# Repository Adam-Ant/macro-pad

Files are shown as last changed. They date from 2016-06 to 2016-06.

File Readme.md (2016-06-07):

# Macro Pad
A project for designing a macro pad to allow complex functions to be mapped to dedicated buttons, using the low cost Arduino Pro Micro. The pad functions by using the inbuilt features of the ATMega32u4 used on the Pro Micro to emulate a gamepad, allowing the buttons to be mapped to many functions. Also includes compatibilty with LED backlighting, including brightness control.

## Parts included:
1. PCB and Schematic in Eagle format and as basic images
2. Firmware for configuring the board to appear as a series of joystick buttons. This is to improve compatibility accross operating systems and programs
3. Case: An example laser cut case for the board. Overview is a general overview of the pieces of the board and assemblly order, Laid out is the pieces optimized for laser cutting.

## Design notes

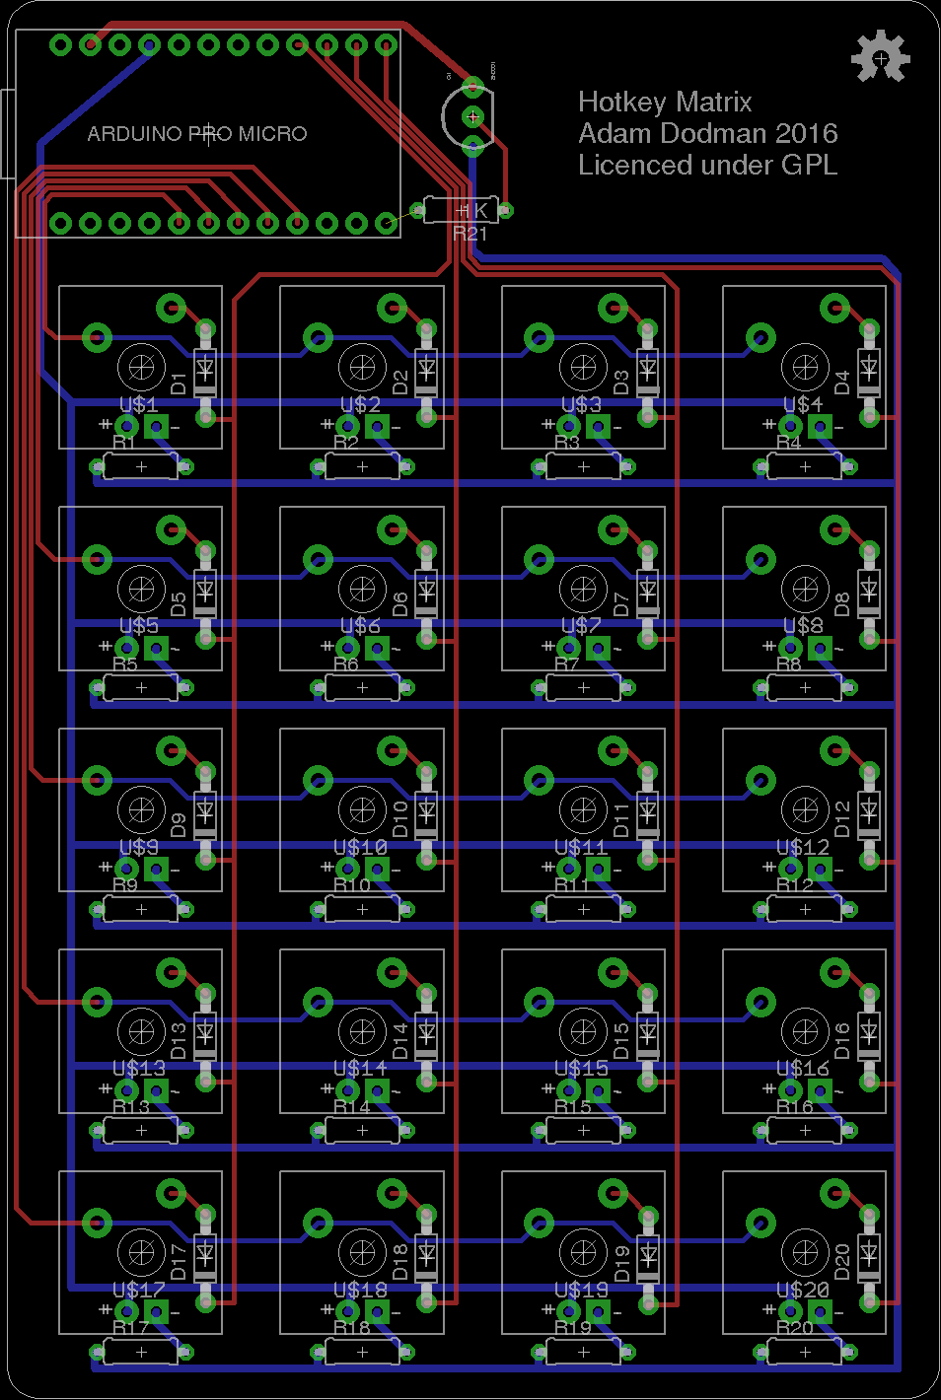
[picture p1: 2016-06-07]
PCB/PCB.png

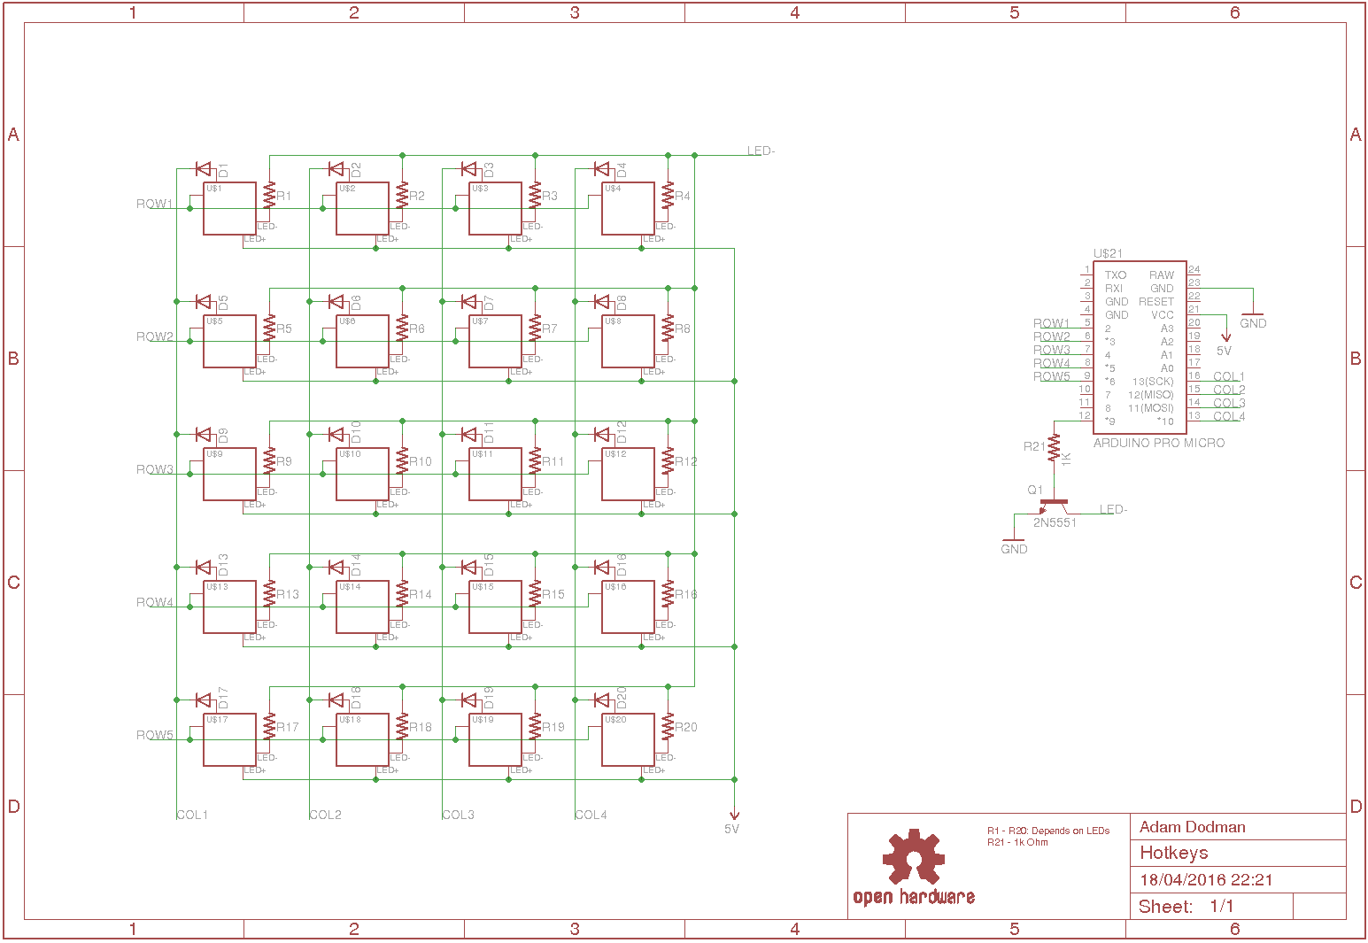
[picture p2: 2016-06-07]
PCB/Scehmatic.png

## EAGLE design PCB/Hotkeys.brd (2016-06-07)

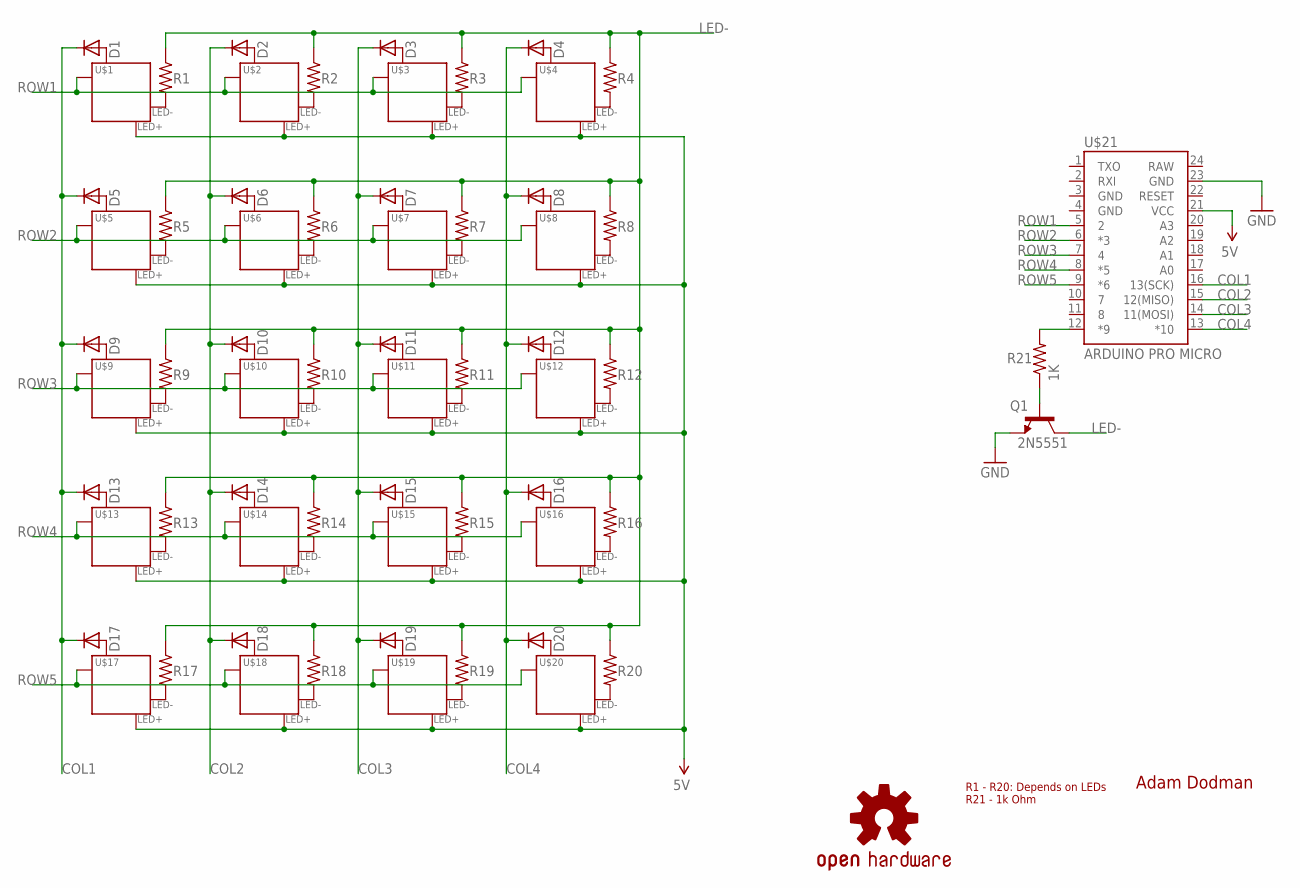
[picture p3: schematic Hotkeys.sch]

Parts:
D1, D2, D3, D4, D5, D6, D7, D8, D9, D10, D11, D12, D13, D14, D15, D16, D17, D18, D19, D20: DIODE-DO41-7.6; DO41-7.6
LOGO1: OSHW-LOGOM; OSHW-LOGO-M
Q1: 2N5551; TO-92-AMMO
R1, R2, R3, R4, R5, R6, R7, R8, R9, R10, R11, R12, R13, R14, R15, R16, R17, R18, R19, R20: R-US_0207/7; 0207/7
R21: 1K; 0207/7
U$1, U$2, U$3, U$4, U$5, U$6, U$7, U$8, U$9, U$10, U$11, U$12, U$13, U$14, U$15, U$16, U$17, U$18, U$19, U$20: MX-1U-LED; P-MX-1U-LED
U$21: ARDUINO PRO MICRO; ARDUINO_PRO_MICRO

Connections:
5V: U$1.LED+, U$2.LED+, U$3.LED+, U$4.LED+, U$5.LED+, U$6.LED+, U$7.LED+, U$8.LED+, U$9.LED+, U$10.LED+, U$11.LED+, U$12.LED+, U$13.LED+, U$14.LED+, U$15.LED+, U$16.LED+, U$17.LED+, U$18.LED+, U$19.LED+, U$20.LED+, U$21.21 (VCC)
COL1: D1.C, D5.C, D9.C, D13.C, D17.C, U$21.16 (13(SCK))
COL2: D2.C, D6.C, D10.C, D14.C, D18.C, U$21.15 (12(MISO))
COL3: D3.C, D7.C, D11.C, D15.C, D19.C, U$21.14 (11(MOSI))
COL4: D4.C, D8.C, D12.C, D16.C, D20.C, U$21.13 (*10)
GND: Q1.3 (E), U$21.23 (GND)
LED-: Q1.1 (C), R1.1, R2.1, R3.1, R4.1, R5.1, R6.1, R7.1, R8.1, R9.1, R10.1, R11.1, R12.1, R13.1, R14.1, R15.1, R16.1, R17.1, R18.1, R19.1, R20.1
unnamed: D1.A, U$1.MX2 (P1)
unnamed: D4.A, U$4.MX2 (P1)
unnamed: D3.A, U$3.MX2 (P1)
unnamed: R2.2, U$2.LED-
unnamed: D5.A, U$5.MX2 (P1)
unnamed: Q1.2 (B), R21.1
unnamed: R1.2, U$1.LED-
unnamed: R3.2, U$3.LED-
unnamed: R4.2, U$4.LED-
unnamed: R21.2, U$21.12 (*9)
unnamed: D6.A, U$6.MX2 (P1)
unnamed: D7.A, U$7.MX2 (P1)
unnamed: D8.A, U$8.MX2 (P1)
unnamed: D9.A, U$9.MX2 (P1)
unnamed: D10.A, U$10.MX2 (P1)
unnamed: D11.A, U$11.MX2 (P1)
unnamed: R5.2, U$5.LED-
unnamed: R6.2, U$6.LED-
unnamed: R7.2, U$7.LED-
unnamed: R8.2, U$8.LED-
unnamed: D12.A, U$12.MX2 (P1)
unnamed: D13.A, U$13.MX2 (P1)
unnamed: D14.A, U$14.MX2 (P1)
unnamed: D15.A, U$15.MX2 (P1)
unnamed: D16.A, U$16.MX2 (P1)
unnamed: D17.A, U$17.MX2 (P1)
unnamed: D18.A, U$18.MX2 (P1)
unnamed: R9.2, U$9.LED-
unnamed: R10.2, U$10.LED-
unnamed: R11.2, U$11.LED-
unnamed: R12.2, U$12.LED-
unnamed: D19.A, U$19.MX2 (P1)
unnamed: D20.A, U$20.MX2 (P1)
unnamed: D2.A, U$2.MX2 (P1)
unnamed: R13.2, U$13.LED-
unnamed: R14.2, U$14.LED-
unnamed: R15.2, U$15.LED-
unnamed: R16.2, U$16.LED-
unnamed: R17.2, U$17.LED-
unnamed: R18.2, U$18.LED-
unnamed: R19.2, U$19.LED-
unnamed: R20.2, U$20.LED-
ROW1: U$1.MX1 (P0), U$2.MX1 (P0), U$3.MX1 (P0), U$4.MX1 (P0), U$21.5 (2)
ROW2: U$5.MX1 (P0), U$6.MX1 (P0), U$7.MX1 (P0), U$8.MX1 (P0), U$21.6 (*3)
ROW3: U$9.MX1 (P0), U$10.MX1 (P0), U$11.MX1 (P0), U$12.MX1 (P0), U$21.7 (4)
ROW4: U$13.MX1 (P0), U$14.MX1 (P0), U$15.MX1 (P0), U$16.MX1 (P0), U$21.8 (*5)
ROW5: U$17.MX1 (P0), U$18.MX1 (P0), U$19.MX1 (P0), U$20.MX1 (P0), U$21.9 (*6)

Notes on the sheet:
Adam Dodman
R1 - R20: Depends on LEDs R21 - 1k Ohm

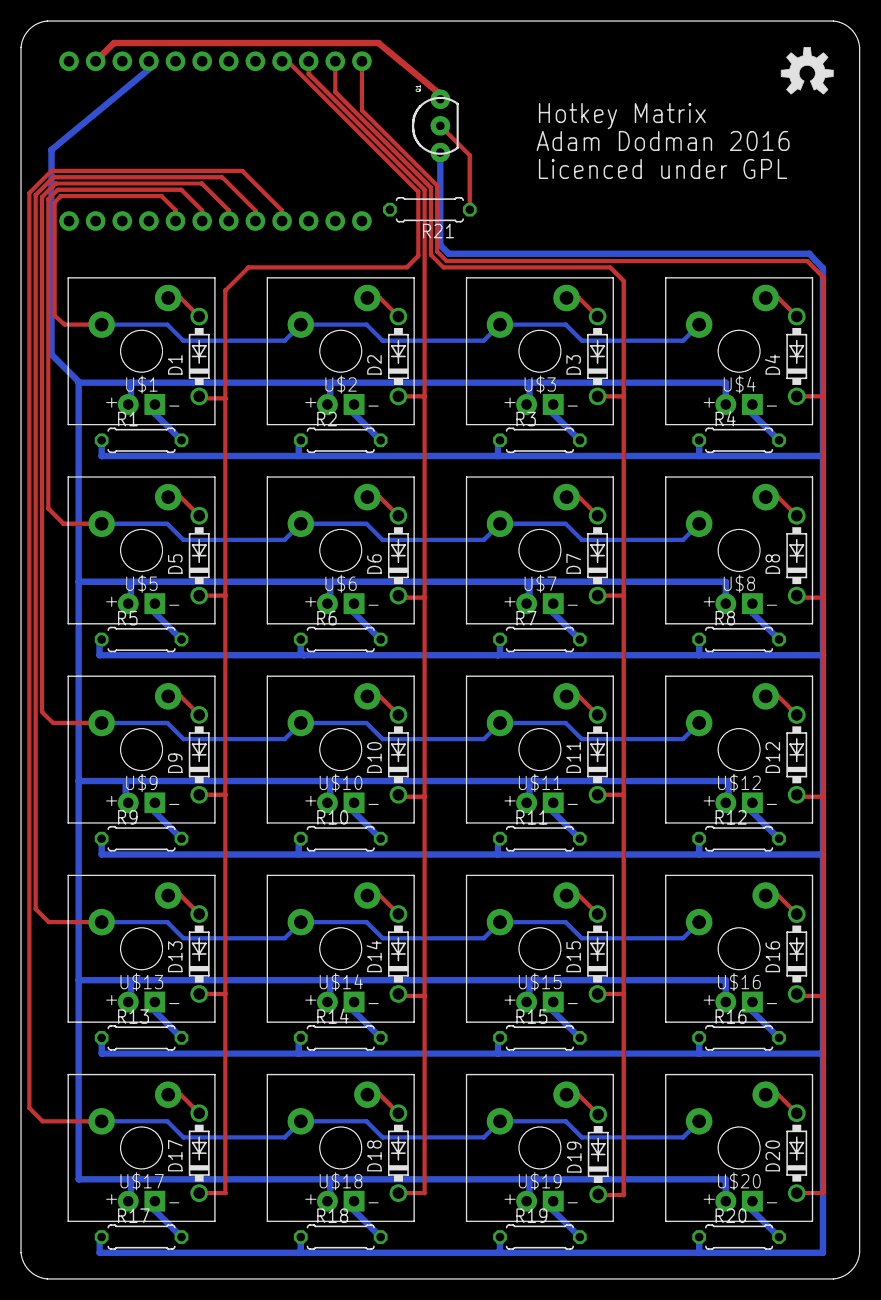
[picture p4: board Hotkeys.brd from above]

Board: 2 copper layers, 80.0 x 120.0 mm, 64 parts (0 on the bottom side), 54 nets.

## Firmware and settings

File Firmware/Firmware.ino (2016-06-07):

#include <Keypad.h>
#include <Joystick.h>
#include <EEPROM.h>

const byte ROWS = 5; //four rows
const byte COLS = 4; //three columns
const int pressdelay = 50;
byte rowPins[ROWS] = { 2, 3, 4, 5, 6 }; //connect to the row pinouts of the keypad
byte colPins[COLS] = { 15, 14, 16, 10 }; //connect to the column pinouts of the keypad
const char keys[ROWS][COLS] = {
  { '0', '1', '2', '3'},
  { '4', '5', '6', '7'},
  { '8', '9', 'a', 'b'},
  { 'c', 'd', 'e', 'f'},
  { 'g', 'h', 'i', 'j'},
};

const int ledPin = 9; 
const int dimVals [] = { 255, 200, 150, 100, 50, 10, 0 };
const int eepromAddress = 88; //Generated by a random external source - griffiths :)
int dimLevel = 6;



Keypad keypad = Keypad( makeKeymap(keys), rowPins, colPins, ROWS, COLS );

void setup(){
  Serial.begin(9600);
  Joystick.begin(false);
  dimLevel = EEPROM.read(eepromAddress);
}


void pressKey(int Key) {
  Joystick.setButton(Key, 1);
  Joystick.sendState();
  delay(pressdelay);
  Joystick.setButton(Key, 0);
  Joystick.sendState();
}

void changeDim (bool level) { //Are we changing the values up or down?
  if (level) { dimLevel -= 1; } // An increase in values means a decrease in brightness!
  else { dimLevel +=1; }
  
  //If we are out of bounds, theres no point updating th\\\\\\e value. Just set it back inside boundries to save EEPROM write cycles.
  if (dimLevel<0) { dimLevel = 0; }
  else if (dimLevel>6){ dimLevel = 6; }
  else { // Looks like the value has changed. Commit it to EEPROM.
    EEPROM.write(eepromAddress, dimLevel);
    Serial.println(dimLevel);
  }
}

void loop(){
  char key = keypad.getKey();
  
  if (key){
    Serial.println(key);
    switch(key){
      case '0':
        //pressKey(0);
        changeDim(false);
        break;
      case '1':
        //pressKey(1);
        changeDim(true);
        break;
      case '2':
        pressKey(2);
        break;
      case '3':
        pressKey(3);
        break;
      case '4':
        pressKey(4);
        break;
      case '5':
        pressKey(5);
        break;
      case '6':
        pressKey(6);
        break;
      case '7':
        pressKey(7);
        break;
      case '8':
        pressKey(8);
        break;
      case '9':
        pressKey(9);
        break;
      case 'a':
        pressKey(10);
        break;
      case 'b':
        pressKey(11);
        break;
      case 'c':
        pressKey(12);
        break;
      case 'd':
        pressKey(13);
        break;
      case 'e':
        pressKey(14);
        break;
      case 'f':
        pressKey(15);
        break;
      case 'g':
        pressKey(16);
        break;
      case 'h':
        pressKey(17);
        break;
      case 'i':
        pressKey(18);
        break;
      case 'j':
        pressKey(19);
        break;
                       
    }
    
   }
   analogWrite(ledPin, dimVals[dimLevel]);
}

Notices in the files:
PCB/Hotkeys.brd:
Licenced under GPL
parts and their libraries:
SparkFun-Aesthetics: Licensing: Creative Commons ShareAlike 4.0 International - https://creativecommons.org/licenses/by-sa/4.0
